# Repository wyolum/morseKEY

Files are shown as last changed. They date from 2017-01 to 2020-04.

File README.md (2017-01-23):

# morseKEY
Morse Code USB Keyboard, from https://mitxela.com/projects/morse_code_usb_keyboard_mk_ii

Morse Key presents itself as a USB keyboard. Typing provides audible feedback via Buzzer, and morse keystrokes get typed on the computer.

## kicad

* [kicad](/kicad) - Main hardware design files. Schematic, Layout etc.

## fabricate

* [fabricate](/fabricate) - 3D CAD files / assembly files

## code

* [code](/code) - FW code

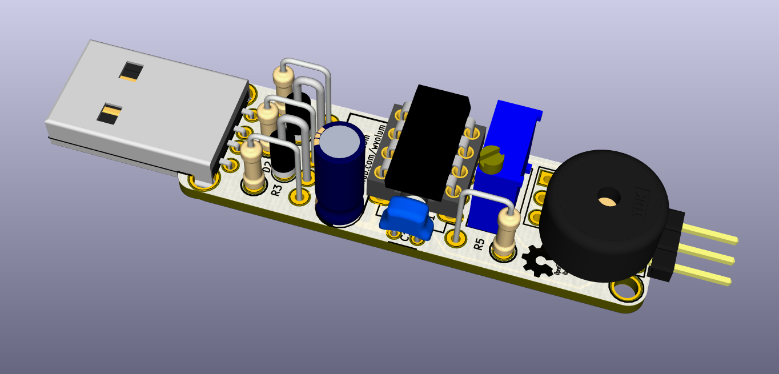
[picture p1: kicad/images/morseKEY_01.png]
morseKEY_top


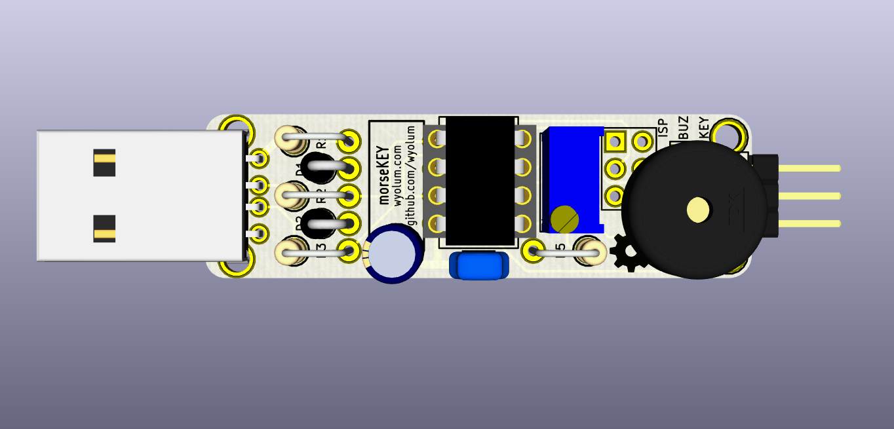
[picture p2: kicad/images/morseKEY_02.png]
morseKEY_bot


License
-------
[CERN Open Hardware Licence v1.2 ]

[CERN Open Hardware Licence v1.2 ]:http://www.ohwr.org/attachments/2388/cern_ohl_v_1_2.txt

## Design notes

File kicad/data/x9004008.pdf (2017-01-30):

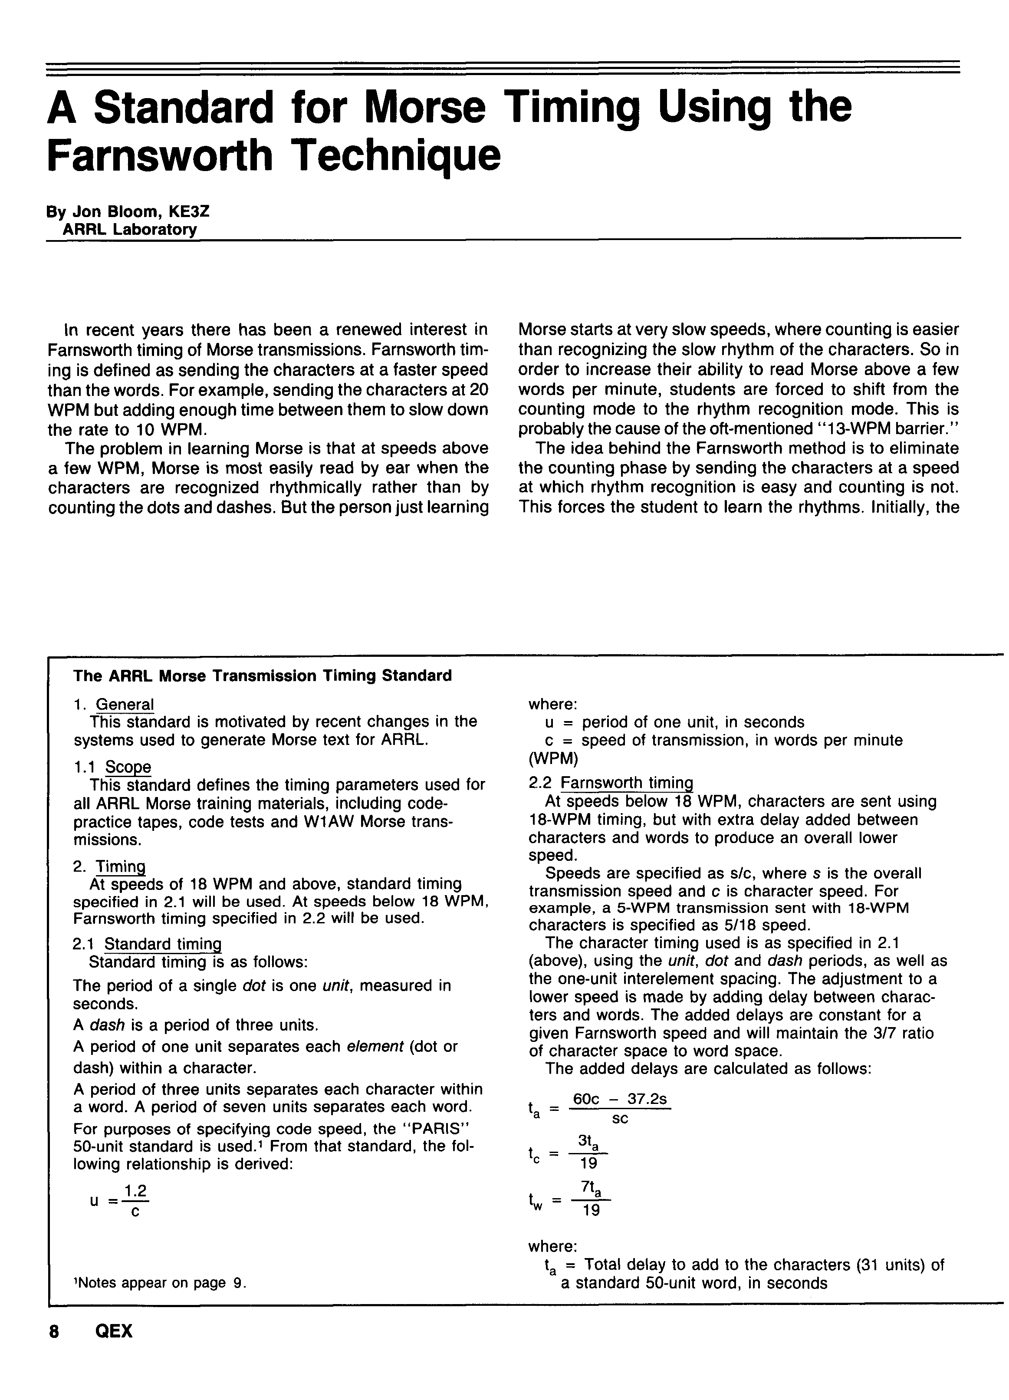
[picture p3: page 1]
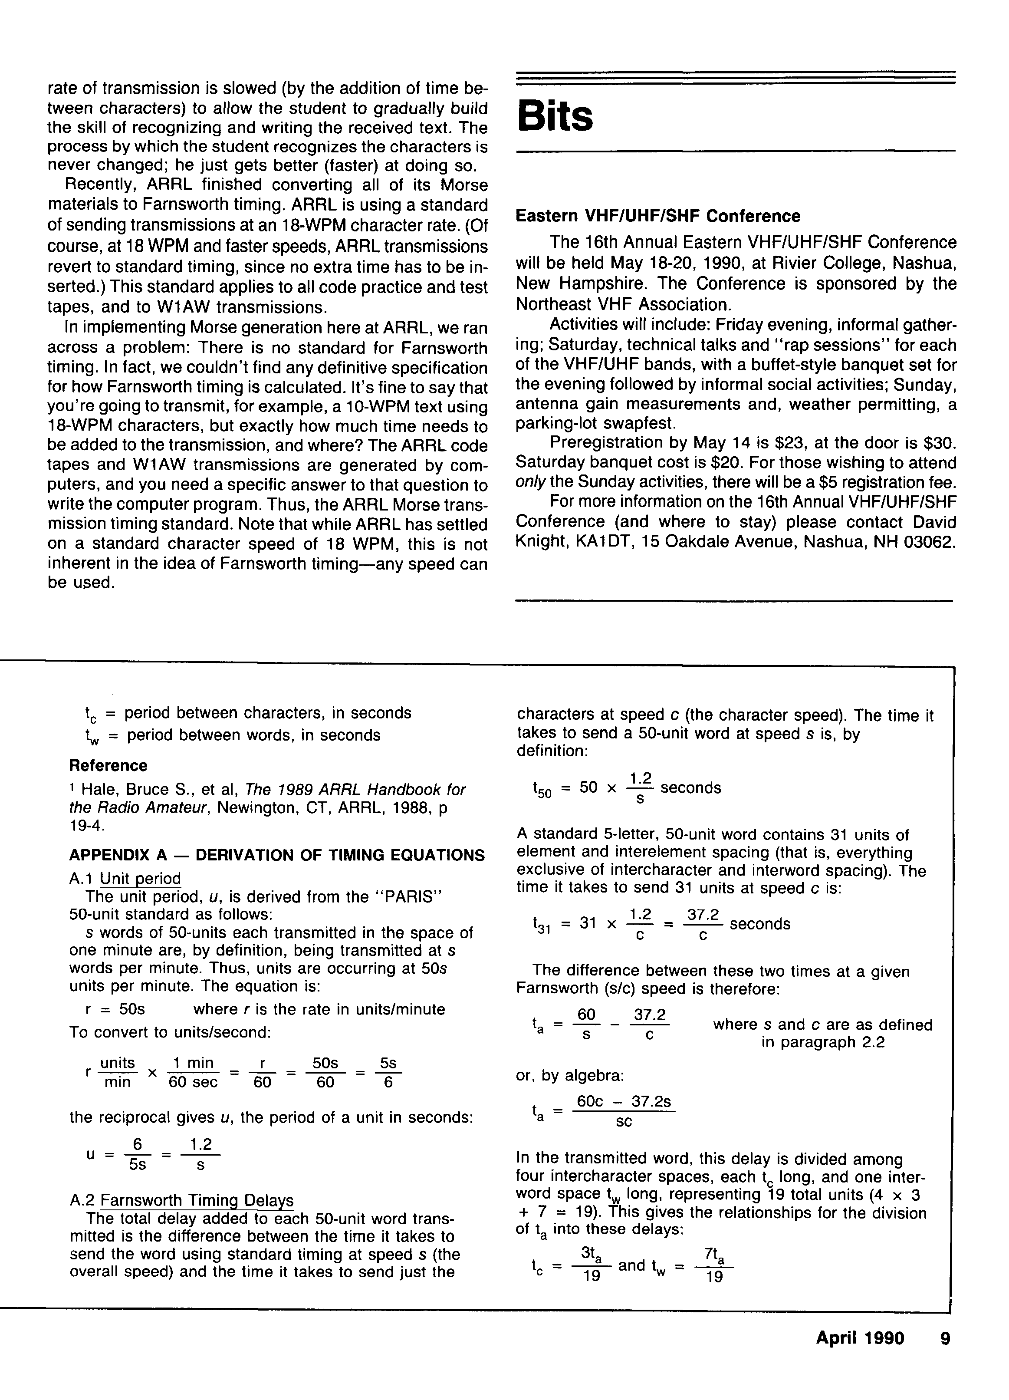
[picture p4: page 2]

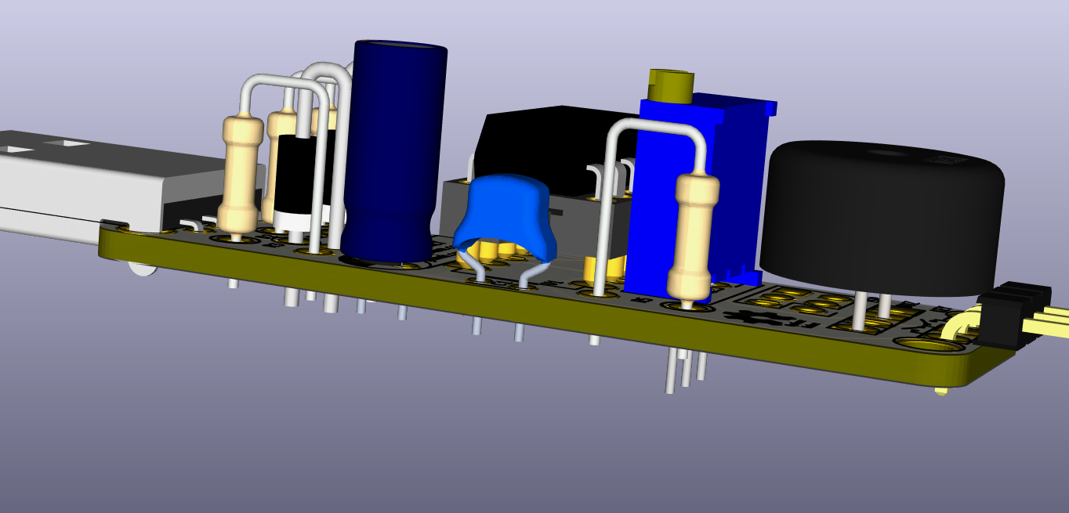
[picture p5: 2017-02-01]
kicad/images/morseKEY_03.png

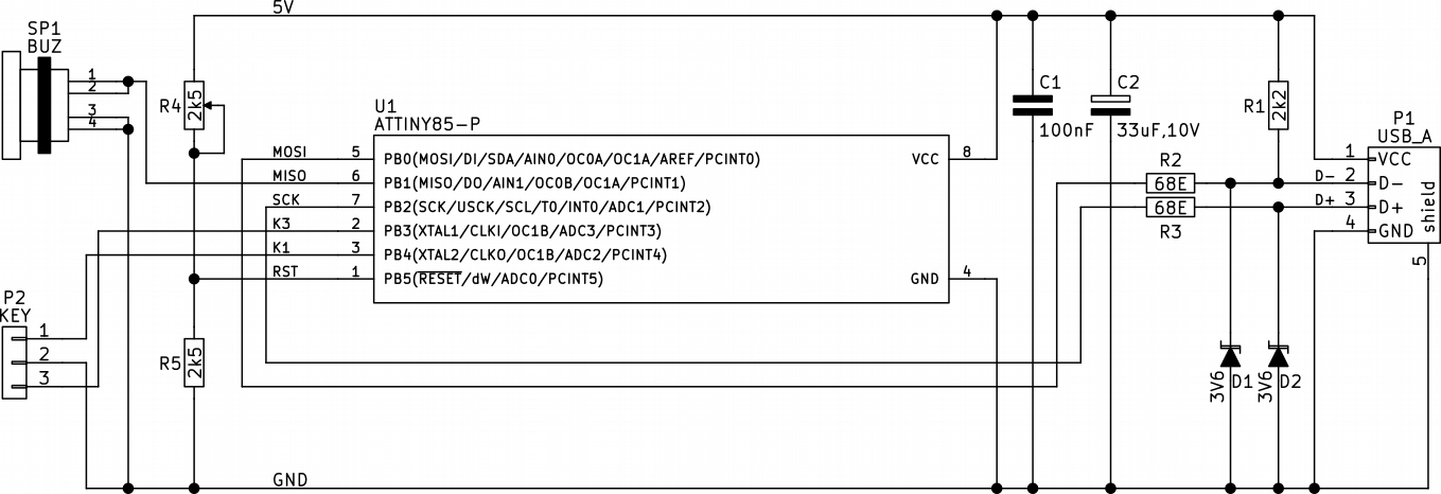
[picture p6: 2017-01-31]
kicad/pdf/morseKEY.sch.jpg

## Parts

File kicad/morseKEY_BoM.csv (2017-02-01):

Id | Designator | Package | Quantity | Designation | Supplier and ref
1 | P3 | Pin_Header_Straight_2x03 | 1 | ISP
2 | C2 | C_Radial_D5_L6_P2.5 | 1 | 33uF,10V
3 | U1 | DIP-8_W7.62mm_LongPads | 1 | ATTINY85-P
4 | SP1 | Pin_Header_Straight_1x04 | 1 | BUZ
5 | P2 | Pin_Header_Straight_1x03 | 1 | KEY
6 | C1 | C_Disc_D3_P2.5 | 1 | 100nF
7 | R4 | res_vert | 1 | 1k5
8 | G1 | OSHW_logo_notext | 1 | OSHW-LOGO
9 | D1,D2 | Diode_DO-41_SOD81_Vertical_KathodeUp_2 | 2 | 3V6
10 | R1 | Resistor_Vertical_RM5mm | 1 | 2k2
11 | R2,R3 | Resistor_Vertical_RM5mm | 2 | 68E
12 | R5 | Resistor_Vertical_RM5mm | 1 | 3k3
13 | G2 | morseKEY | 1 | CKT
14 | P4,P5 | 1pin | 2 | MTG
15 | P1 | USB_A_up2-ah-th | 1 | USB_A

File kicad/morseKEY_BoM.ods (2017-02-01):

Id | Designator | Package | Quantity | Designation | Mfr P/N | Digikey P/N | Link
1 | C1 | Disc, 2.5mm/0.1” pitch | 1 | 100nF | C320C104K5R5TA | 399-4264-ND | http://www.digikey.com/product-detail/en/kemet/C320C104K5R5TA/399-4264-ND/818040
2 | C2 | Radial, 5mm dia, 2.5mm/0.1” pitch | 1 | 33uF,10V | 860020473007 | 732-8824-1-ND | http://www.digikey.com/product-detail/en/wurth-electronics-inc/860020473007/732-8824-1-ND/5728769
3 | D1,D2 | Diode, DO-41 | 2 | 3V6 | 1N5227B | 1N5227B-ND | http://www.digikey.com/product-detail/en/fairchild-on-semiconductor/1N5227B/1N5227B-ND/977563
4 | P1 | USB_A_up2-ah-th | 1 | USB_A | UP2-AH-1-TH | 102-3996-ND | http://www.digikey.com/product-detail/en/cui-inc/UP2-AH-1-TH/102-3996-ND/6187911
5 | P2 | Pin_Header_Straight_1x03 | 1 | KEY | -- | -- | --
6 | P3 | Pin_Header_Straight_2x03 | 1 | ISP | -- | -- | --
7 | R1 | Resistor, 1/4W | 1 | 2k2 | CF18JT2K20 | CF18JT2K20CT-ND | http://www.digikey.com/product-detail/en/stackpole-electronics-inc/CF18JT2K20/CF18JT2K20CT-ND/2022750
8 | R2,R3 | Resistor, 1/4W | 2 | 68E | CF18JT68R0 | CF18JT68R0CT-ND | http://www.digikey.com/product-detail/en/stackpole-electronics-inc/CF18JT68R0/CF18JT68R0CT-ND/2022714
9 | R4 | Trimpot, vertical, in-line leads | 1 | 1k5 | PV36W202C01B00 | 490-2880-ND | http://www.digikey.com/product-detail/en/bourns-inc/PV36W202C01B00/490-2880-ND/666507
10 | R5 | Resistor, 1/4W | 1 | 3k3 | CF18JT3K30 | CF18JT3K30CT-ND | http://www.digikey.com/product-detail/en/stackpole-electronics-inc/CF18JT3K30/CF18JT3K30CT-ND/2022754
11 | SP1 | Buzzer, Piezo, 12.2mm dia, 5mm pitch | 1 | BUZ | PS1440P02BT | 445-5242-1-ND | http://www.digikey.com/product-detail/en/tdk-corporation/PS1440P02BT/445-5242-1-ND/2236832
12 | U1 | DIP-8 | 1 | ATTINY85-P | ATTINY85-20PU | ATTINY85-20PU-ND | http://www.digikey.com/product-detail/en/microchip-technology/ATTINY85-20PU/ATTINY85-20PU-ND/735469
13 | UI_socket | socket, DIP-8 | 1 | -- | ED08DT | ED3044-5-ND | http://www.digikey.com/product-detail/en/on-shore-technology-inc/ED08DT/ED3044-5-ND/4147594

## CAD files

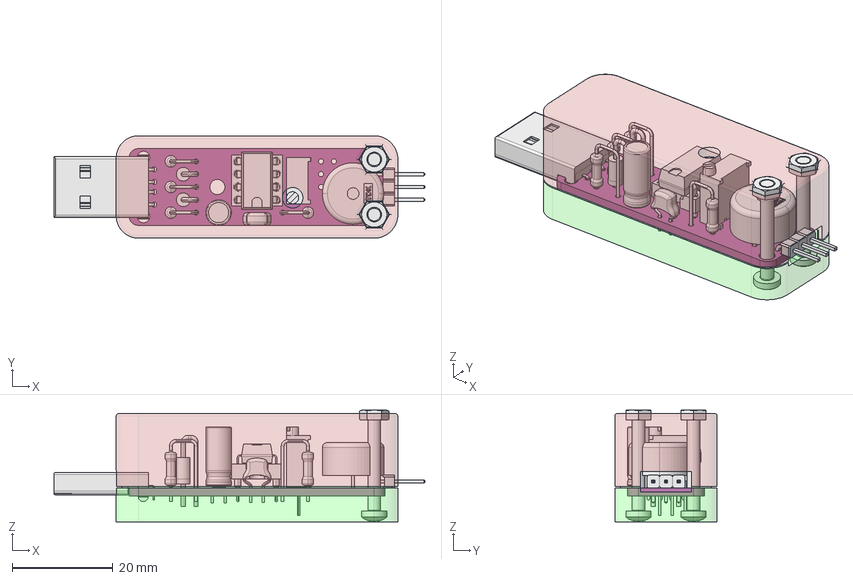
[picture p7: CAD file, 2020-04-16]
fabricate/morseKEY.FCStd
73.6 x 20.3 x 22.2 mm
bottom
top
M2.5x20-Screw
M2.5x20-Screw001
M2.5-Nut
M2.5-Nut001
Pcb_ee89
cap_elco_R100_D200_H460
ic_dip_8
PS1240P02BT003
PS1240P02BT004
PS1240P02BT005
header_Male_RA_Low_3Pin
cap_cer_FK18X5R1E474K
trimpot_vert
diode_vert x 2
res_vert x 4
usb_a

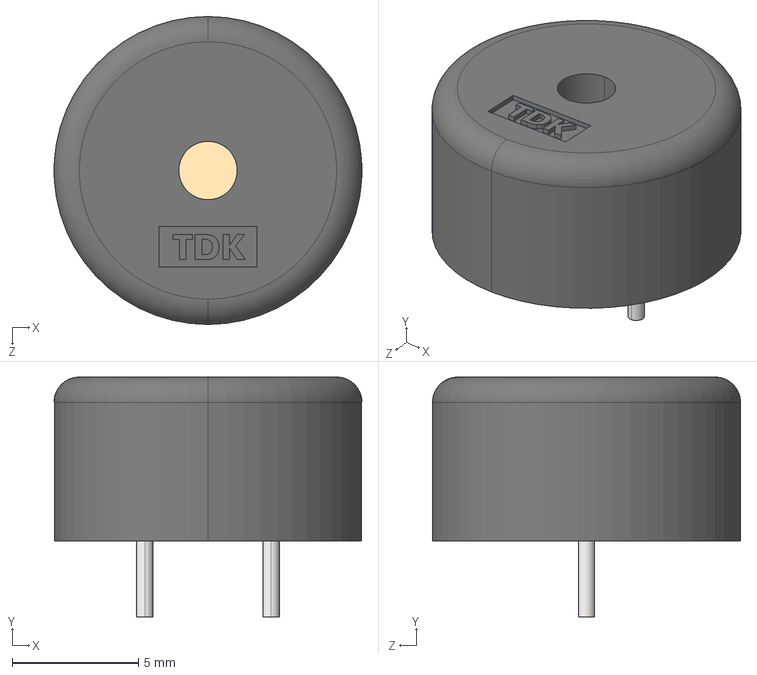
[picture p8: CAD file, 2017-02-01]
kicad/3d/piezo_PS1240P02BT.step
12.2 x 9.50 x 12.2 mm

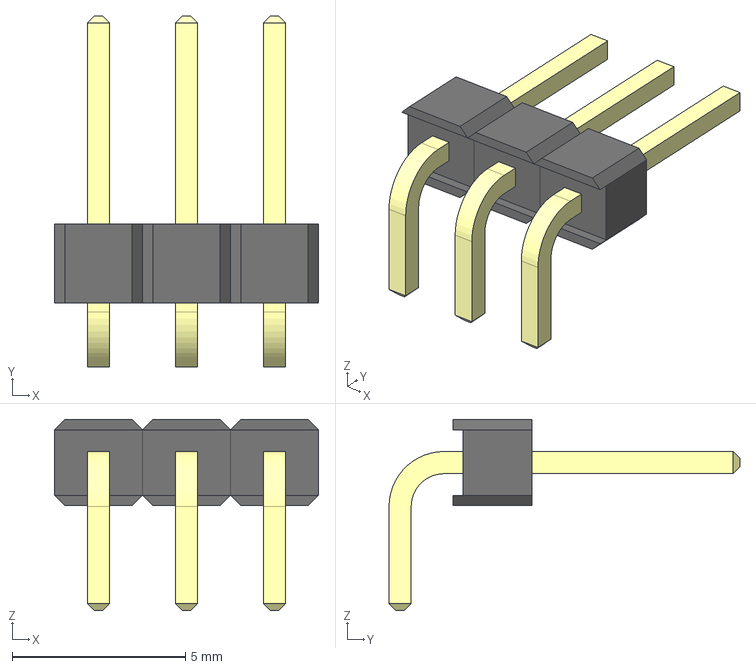
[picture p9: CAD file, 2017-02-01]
kicad/3d/header_Male_RA_Low_3Pin.step
7.62 x 10.1 x 5.52 mm

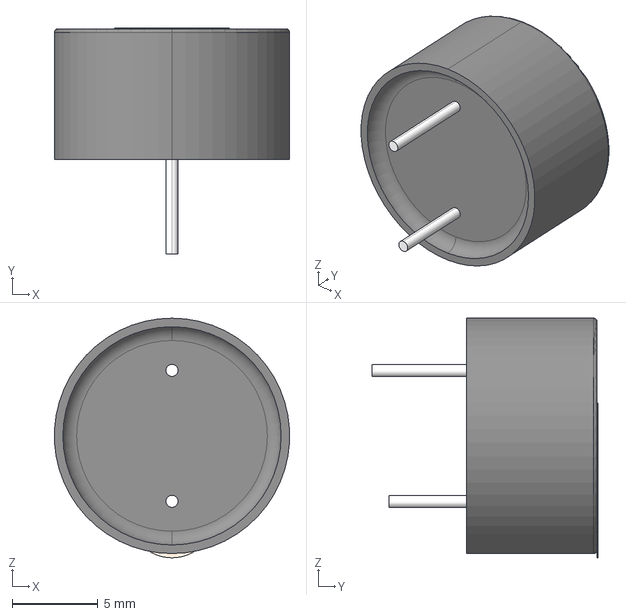
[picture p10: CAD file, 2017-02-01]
kicad/3d/piezo_CPE-164.stp
13.7 x 13.2 x 13.9 mm

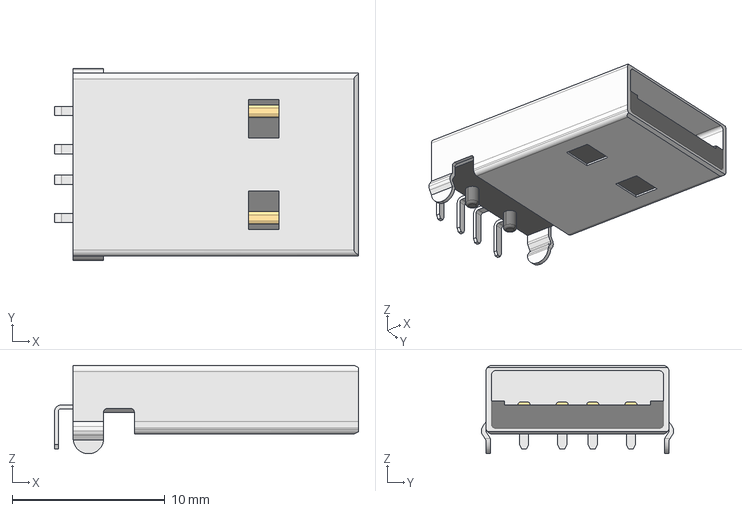
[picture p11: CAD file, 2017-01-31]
kicad/3d/usb_a.step
19.9 x 12.6 x 5.80 mm

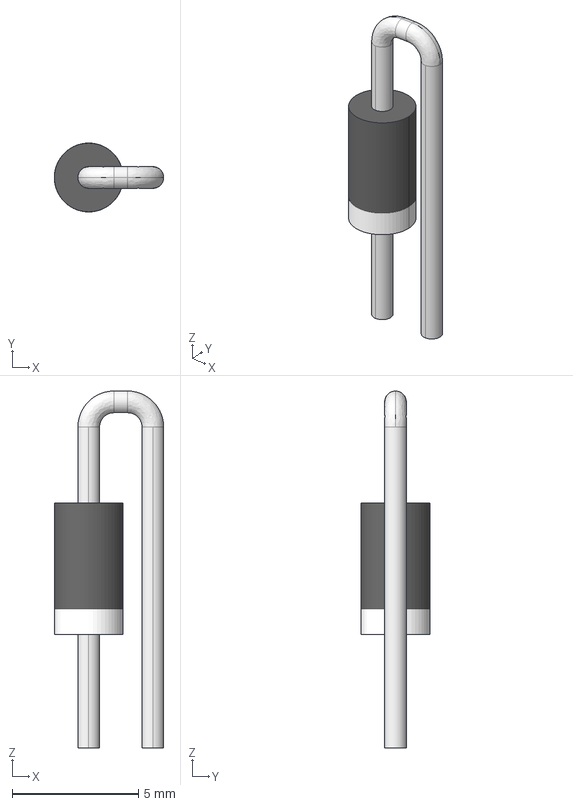
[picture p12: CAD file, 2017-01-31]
kicad/3d/diode_vert.step
4.33 x 2.73 x 14.1 mm

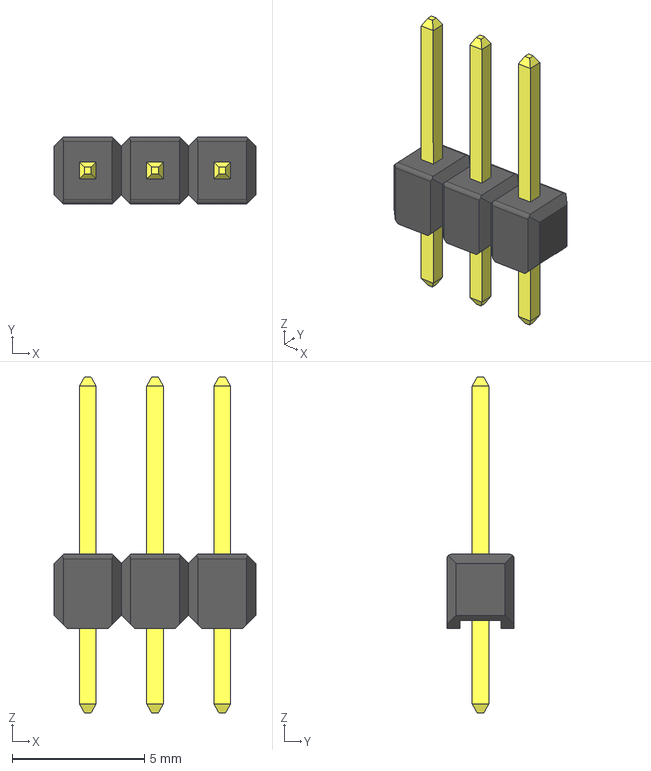
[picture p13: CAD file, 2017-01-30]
kicad/3d/header_1x3_TH_2_54mm.step
7.62 x 2.54 x 12.7 mm

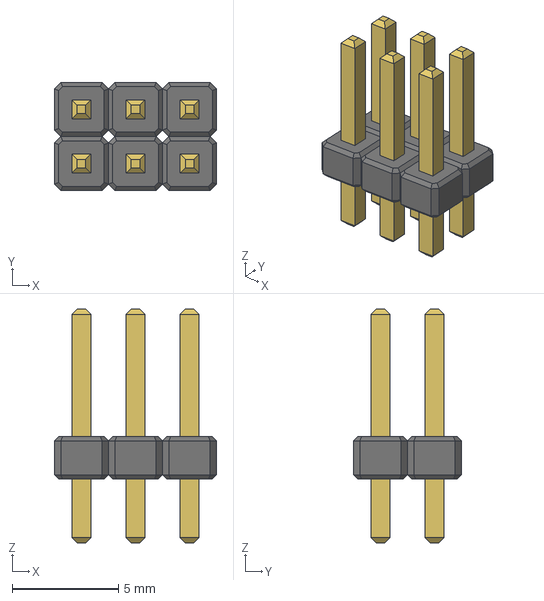
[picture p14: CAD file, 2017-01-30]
kicad/3d/header_2x3_TH_2_54mm.step
7.62 x 5.08 x 11.0 mm

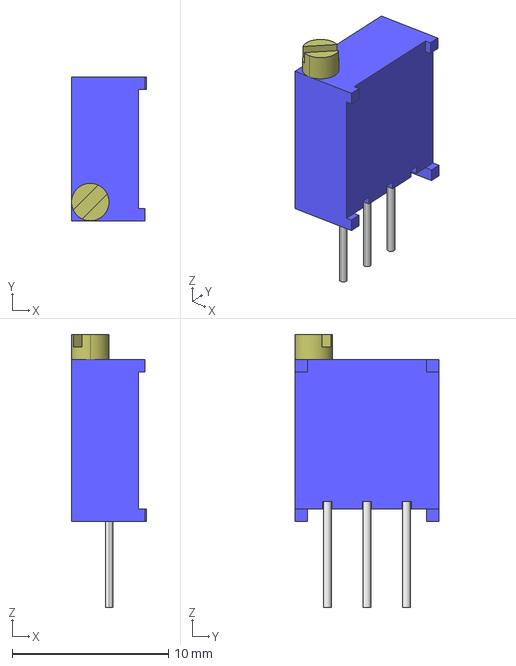
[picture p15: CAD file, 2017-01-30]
kicad/3d/trimpot_vert.step
4.80 x 9.20 x 17.5 mm

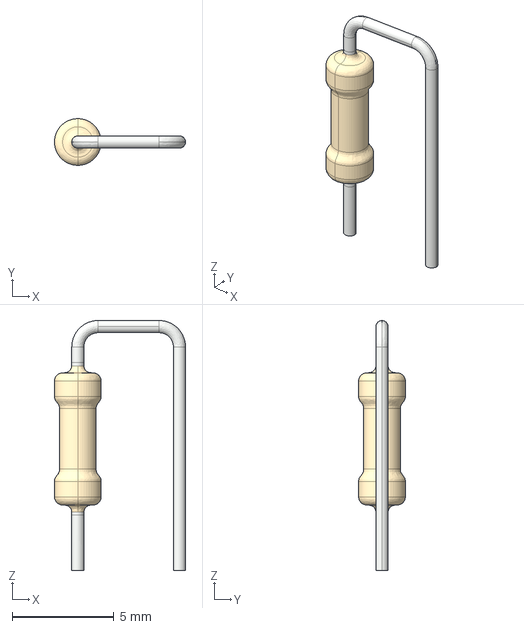
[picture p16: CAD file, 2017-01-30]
kicad/3d/res_vert.step
6.45 x 2.30 x 12.3 mm

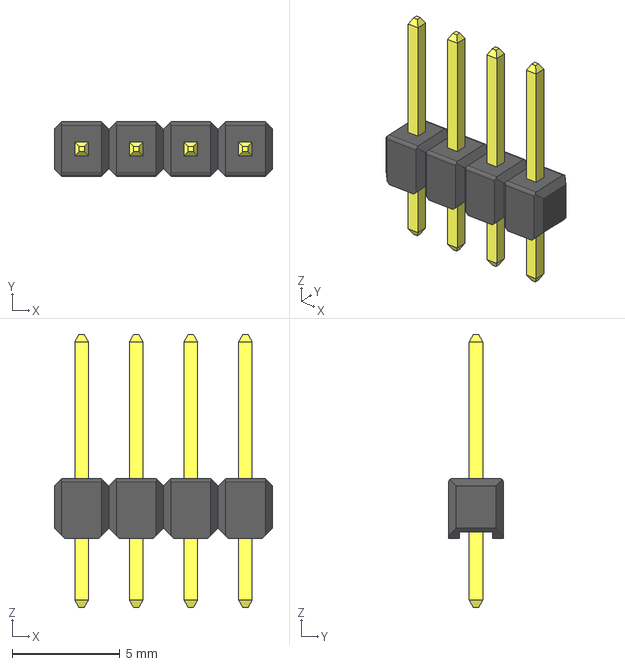
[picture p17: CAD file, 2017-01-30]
kicad/3d/header_1x4_TH_2_54mm.step
10.2 x 2.54 x 12.7 mm

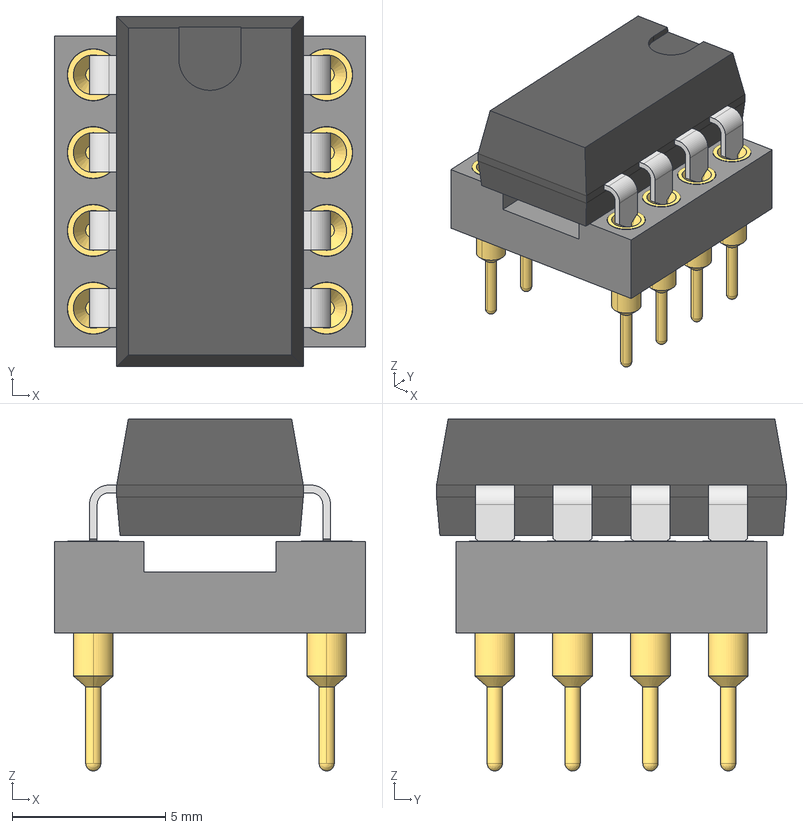
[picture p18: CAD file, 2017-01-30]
kicad/3d/ic_dip_8.step
10.2 x 11.4 x 11.5 mm

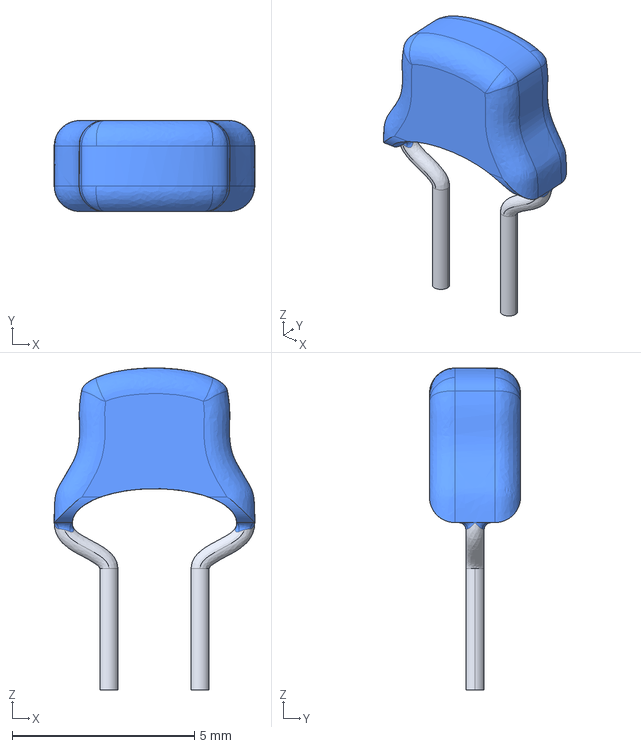
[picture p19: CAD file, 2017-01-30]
kicad/3d/cap_cer_FK18X5R1E474K.step
5.50 x 2.50 x 8.83 mm

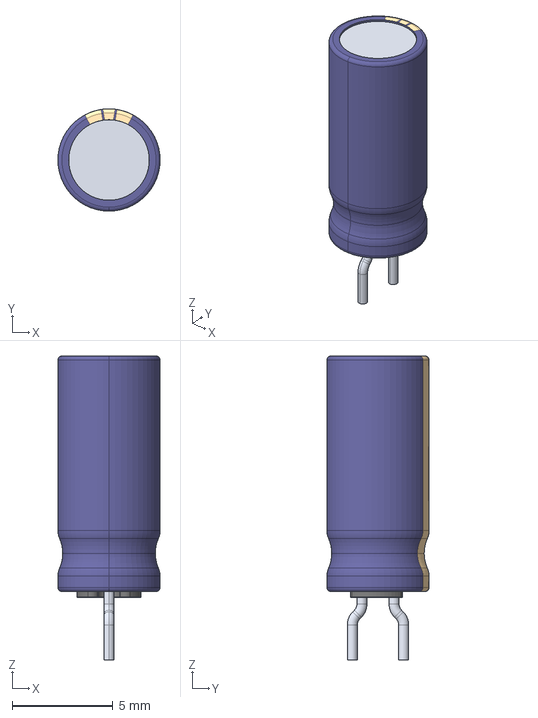
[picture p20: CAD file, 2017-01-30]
kicad/3d/cap_elco_R100_D200_H460.step
5.08 x 5.08 x 15.1 mm

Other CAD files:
kicad/3d/PS1240P02BT.step
kicad/3d/archive/trimpot_vert.step
kicad/3d/archive/cap_elco_ra.step
kicad/3d/archive/usb_a_th.step
kicad/3d/archive/8pin_0_3x2_54mm_DIP_Socket.step
kicad/3d/archive/DIP8.step
kicad/3d/archive/cap_cer-FK18X5R1E474K.step
kicad/3d/archive/cap_cer_3_5x1_5.step
kicad/3d/archive/cap_elco_R100_D200_H460.step
kicad/3d/archive/cap_elec_6_3x11x2_5mm RA.step
kicad/3d/archive/diode_DO-41_vert.step
kicad/3d/archive/pot_vertical.step
kicad/3d/archive/res_vert_0_25W.step

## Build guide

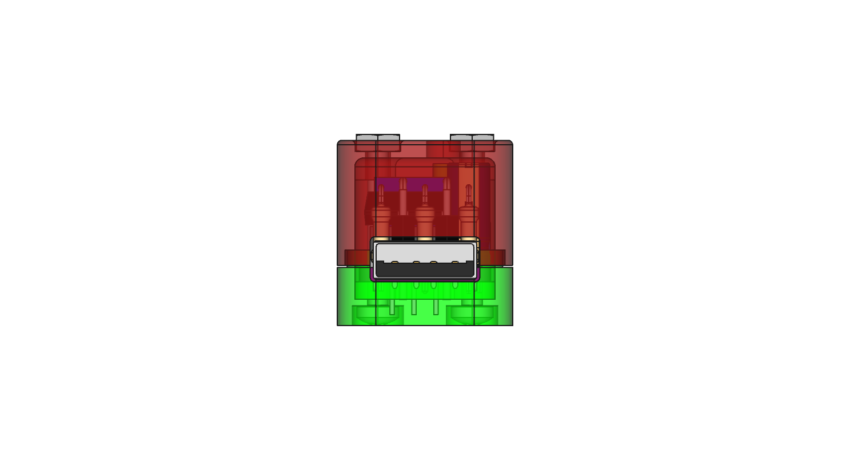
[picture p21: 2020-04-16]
fabricate/renders/morsekey_enc_05.png

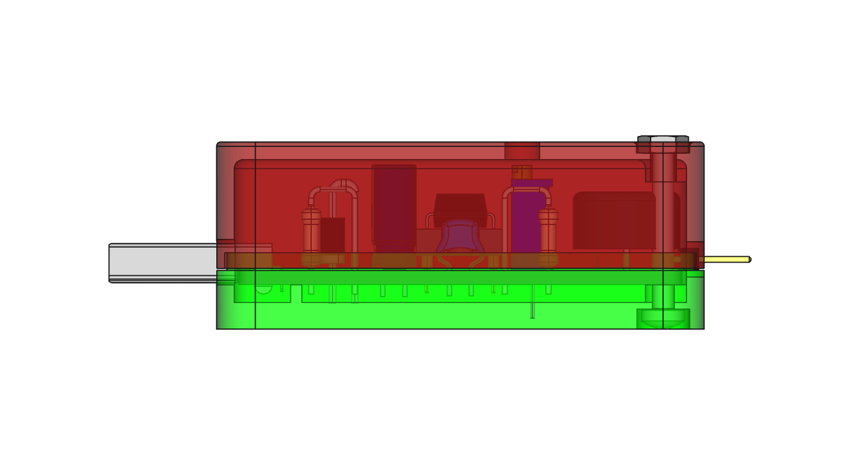
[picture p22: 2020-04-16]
fabricate/renders/morsekey_enc_02.png

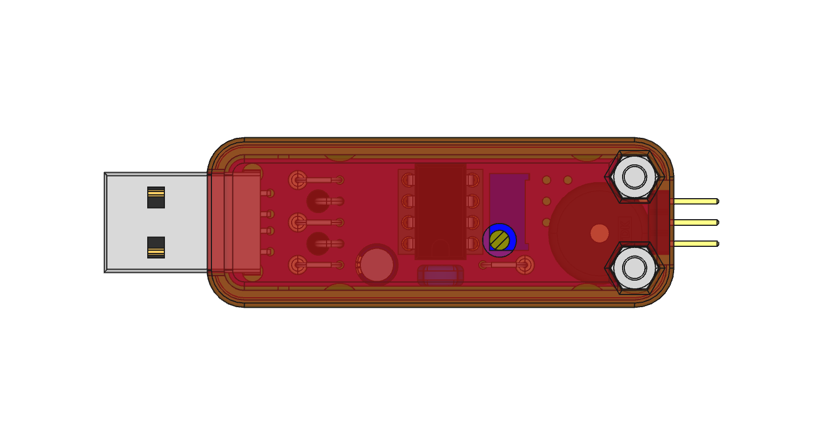
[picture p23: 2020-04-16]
fabricate/renders/morsekey_enc_03.png

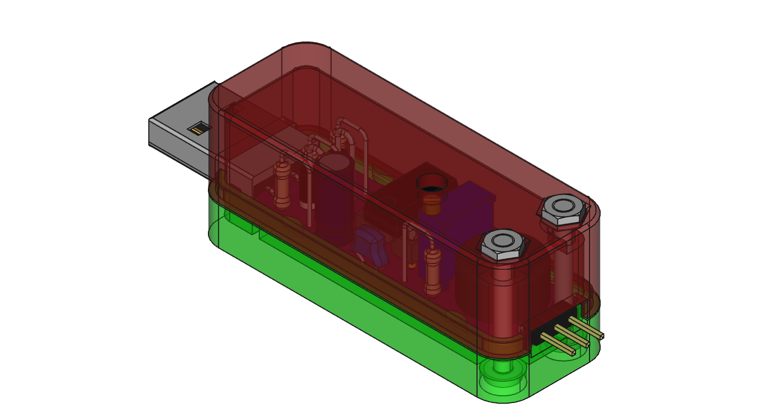
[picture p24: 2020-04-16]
fabricate/renders/morsekey_enc_01.png

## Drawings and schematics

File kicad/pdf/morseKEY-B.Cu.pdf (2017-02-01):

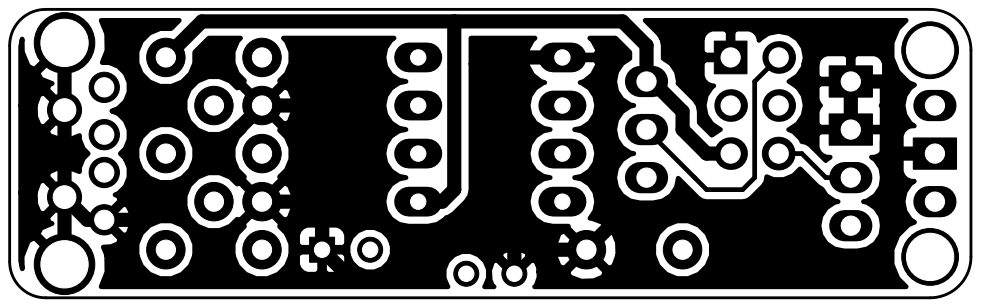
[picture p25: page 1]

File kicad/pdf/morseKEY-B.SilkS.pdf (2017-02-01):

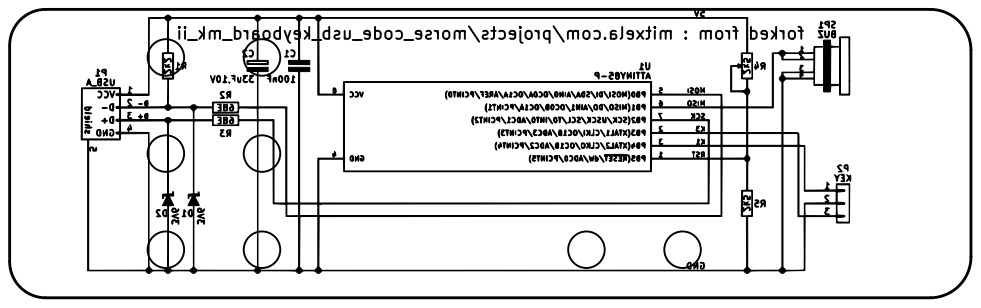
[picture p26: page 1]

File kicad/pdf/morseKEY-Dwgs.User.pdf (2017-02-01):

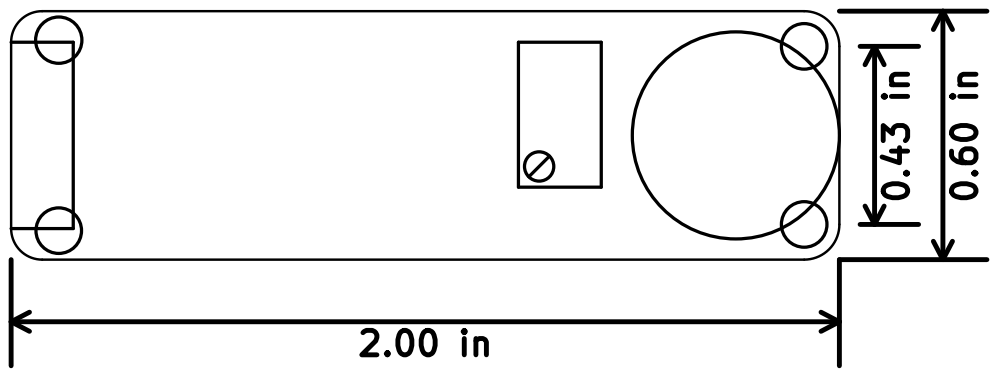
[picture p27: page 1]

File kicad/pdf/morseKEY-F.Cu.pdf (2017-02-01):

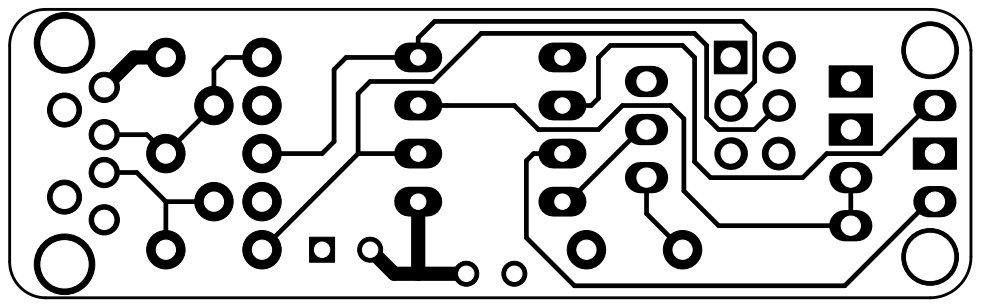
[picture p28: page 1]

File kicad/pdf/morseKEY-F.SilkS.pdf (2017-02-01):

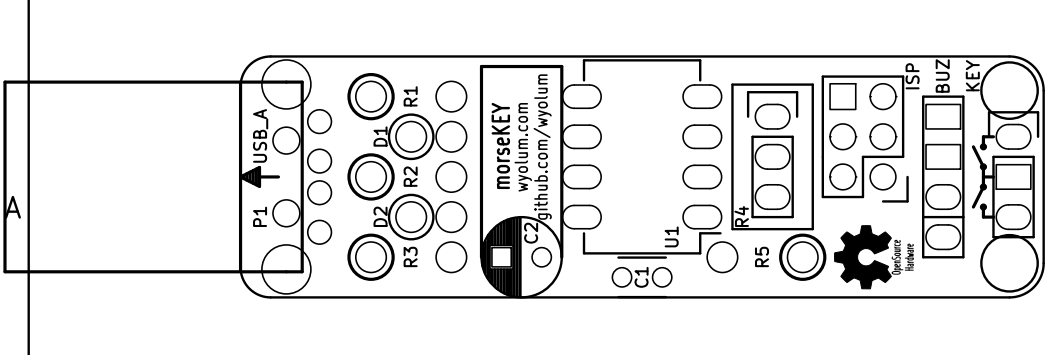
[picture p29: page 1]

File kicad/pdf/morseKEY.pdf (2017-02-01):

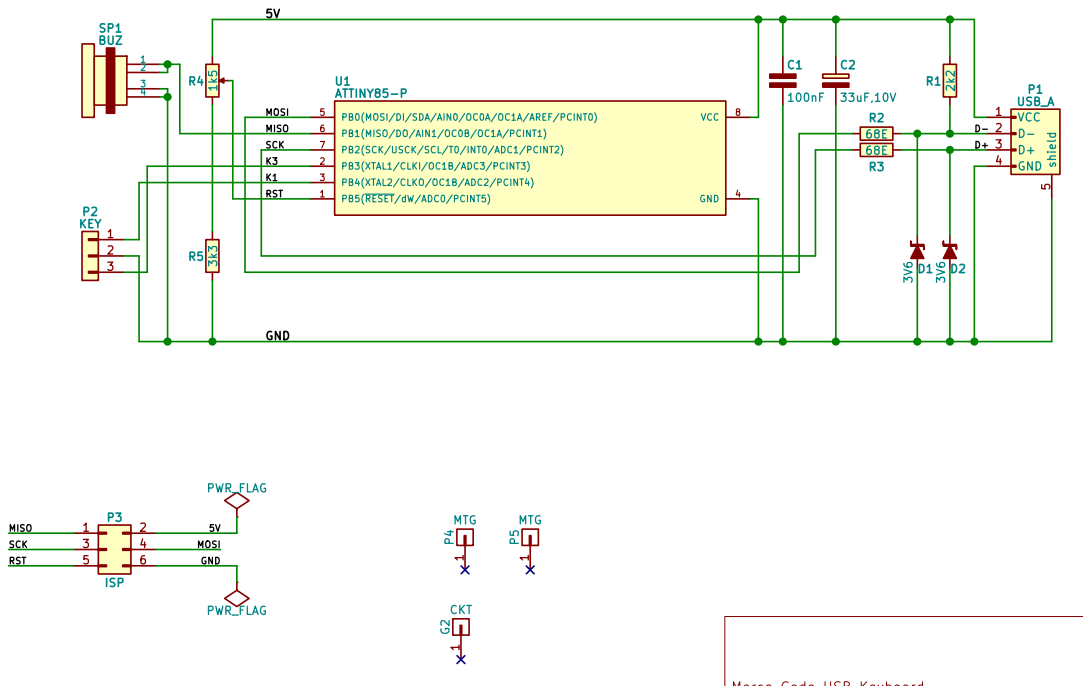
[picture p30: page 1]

Morse Code USB Keyboard
File: morseKEY.sch Sheet: / WyoLum

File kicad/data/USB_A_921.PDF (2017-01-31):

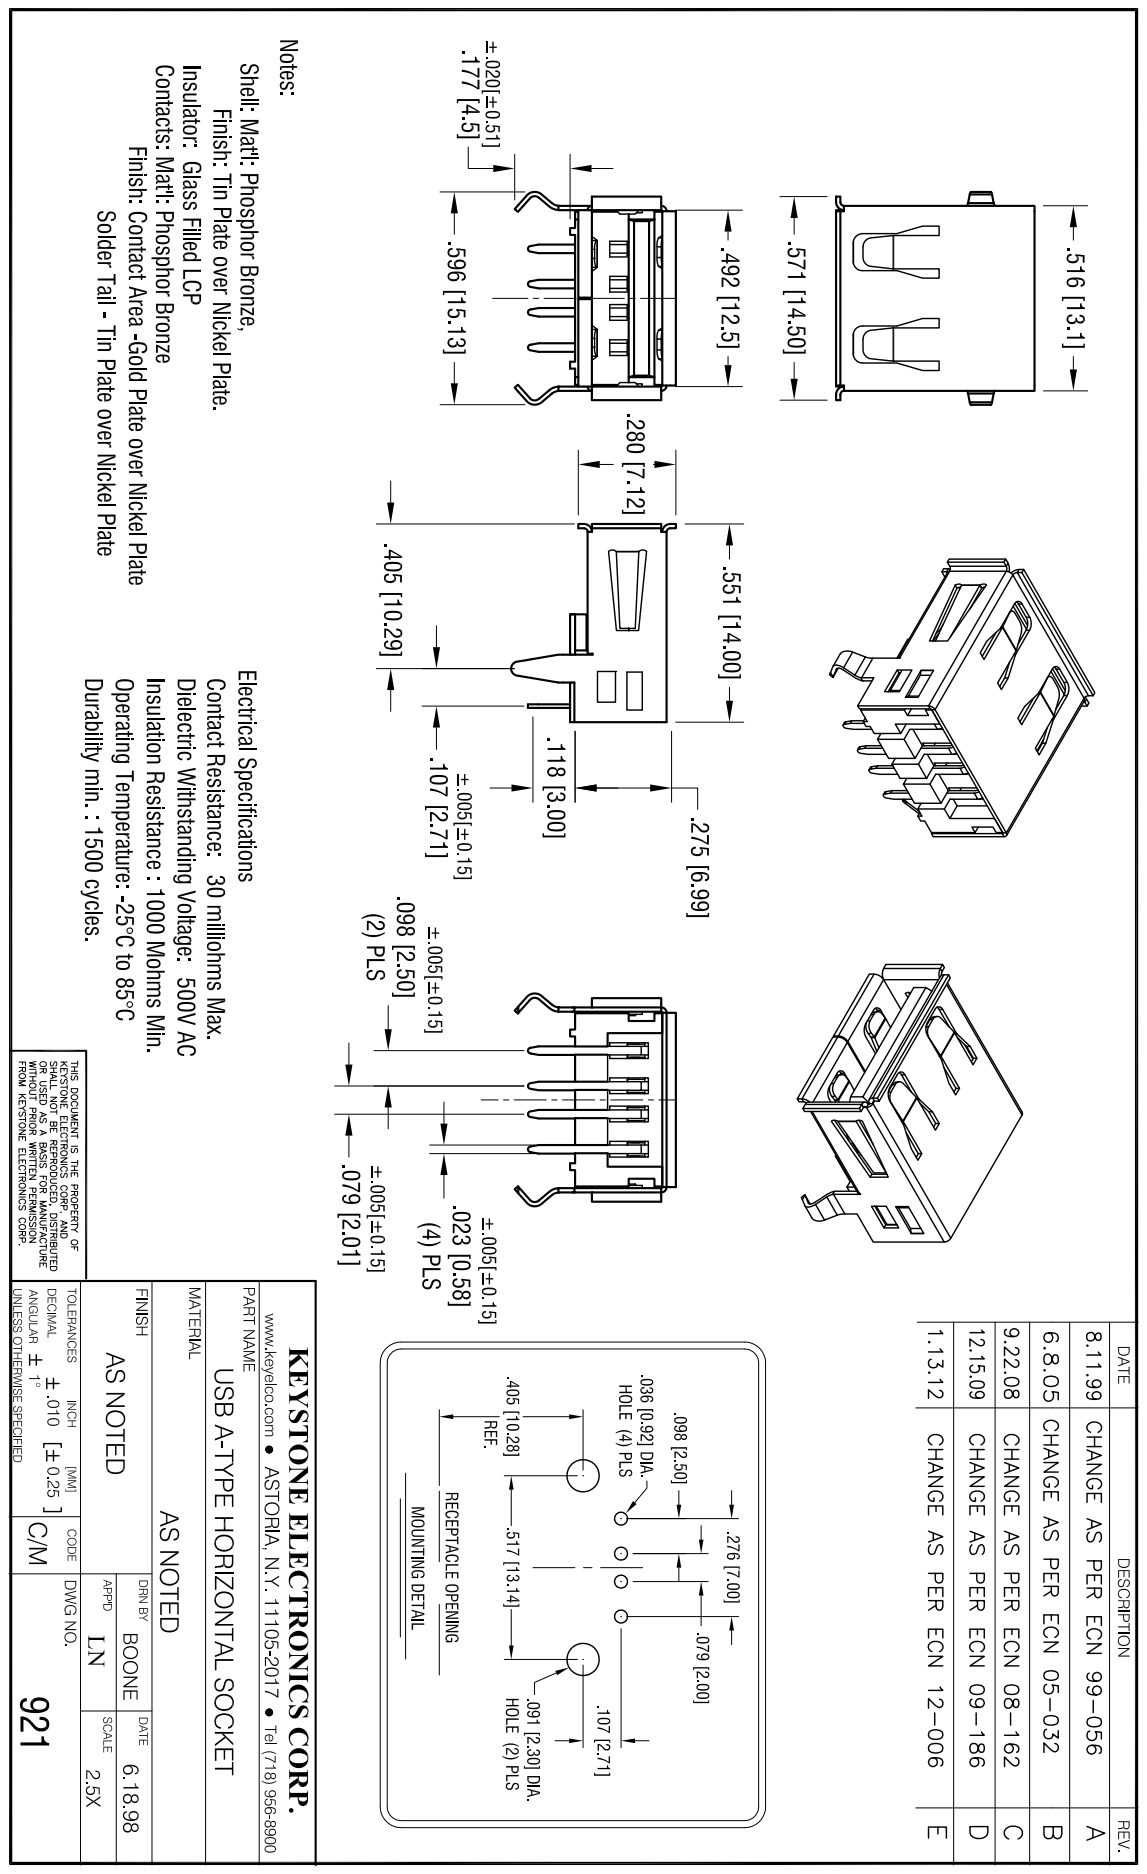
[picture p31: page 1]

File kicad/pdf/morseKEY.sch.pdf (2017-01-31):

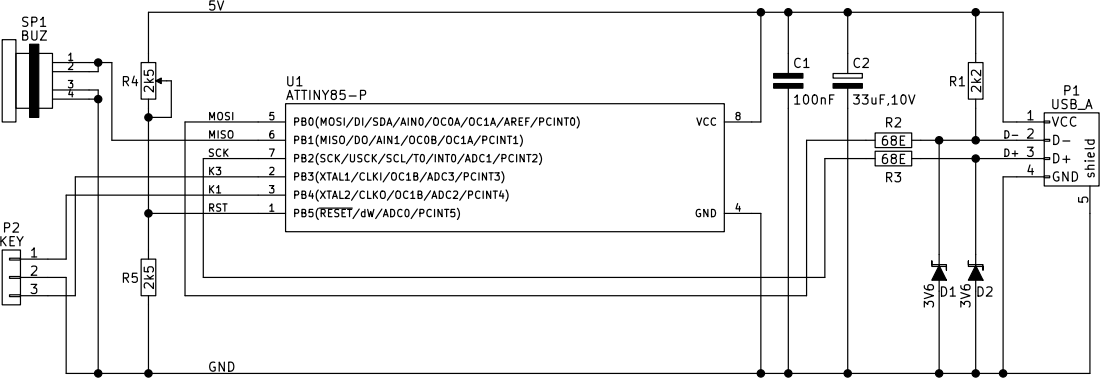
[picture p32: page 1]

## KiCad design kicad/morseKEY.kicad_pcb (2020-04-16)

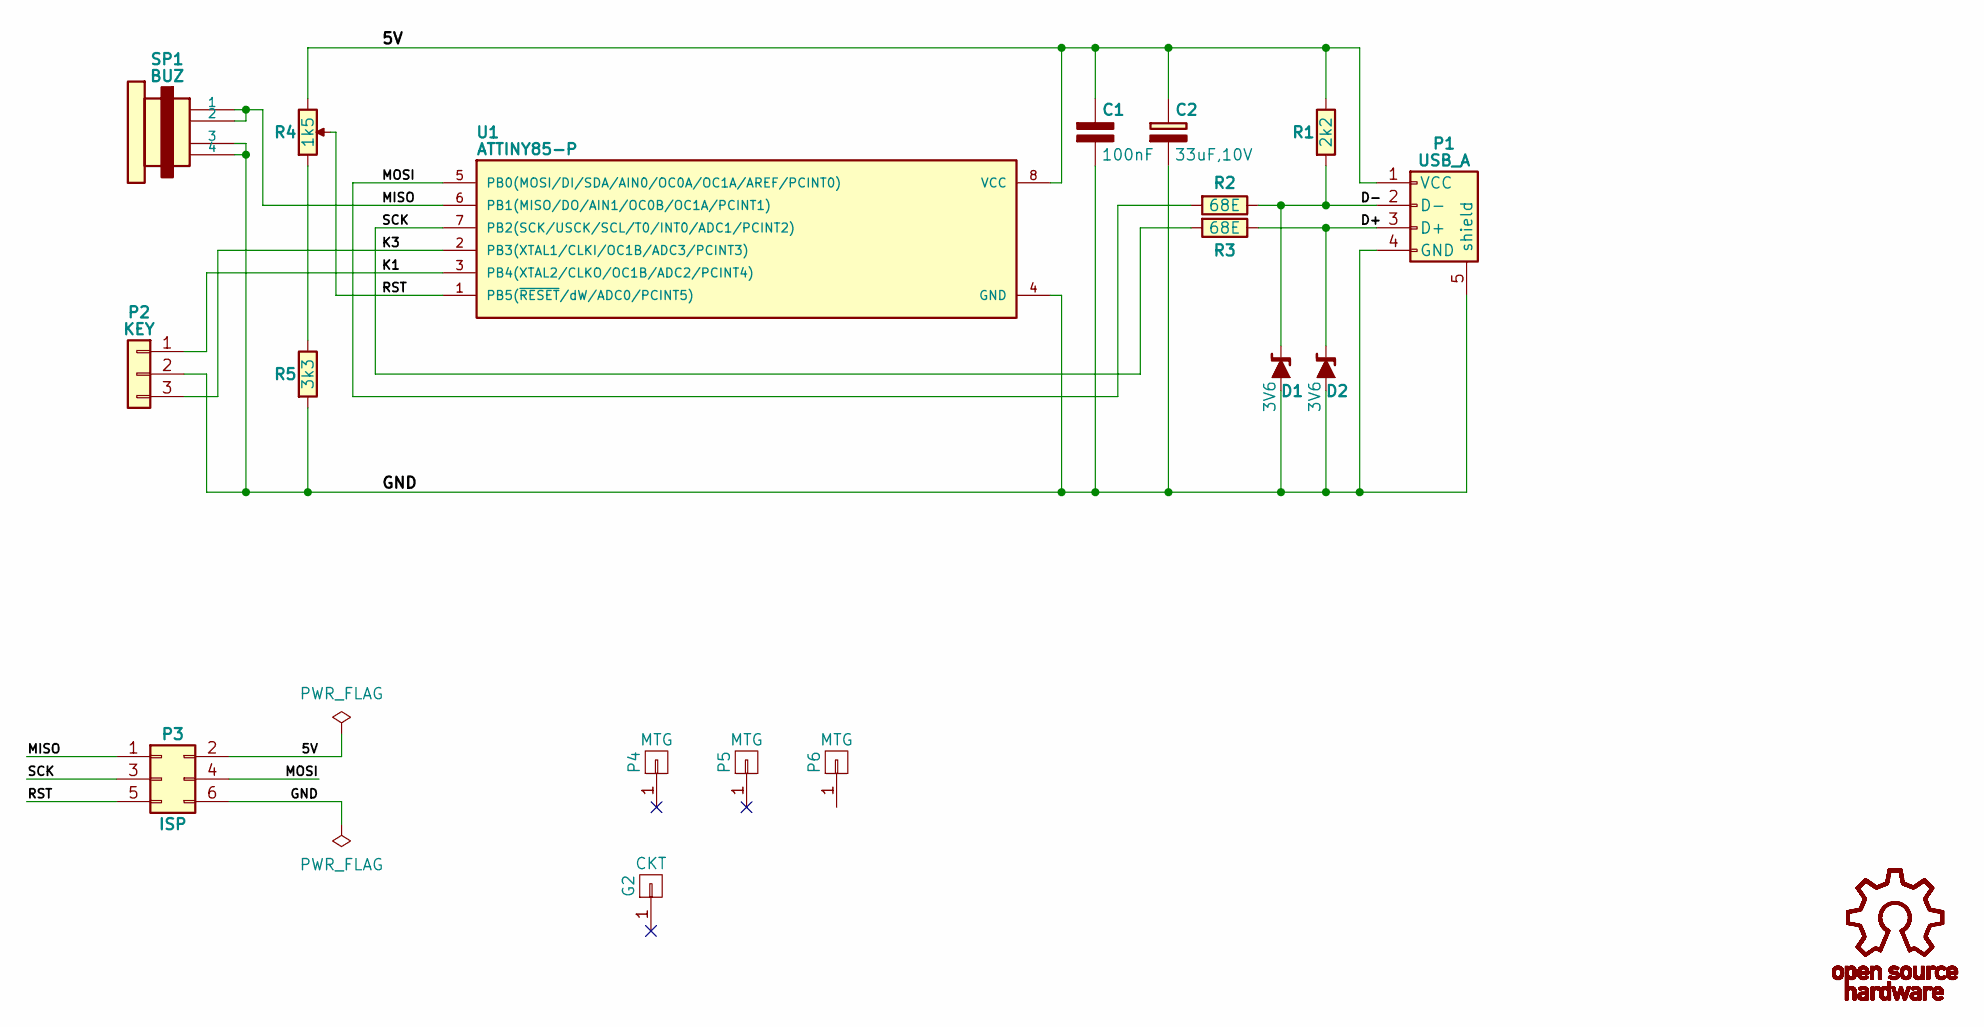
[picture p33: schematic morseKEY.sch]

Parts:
C1: 100nF; C_Disc_D3_P2.5
C2: 33uF,10V; C_Radial_D5_L6_P2.5
D1, D2: 3V6; Diode_DO-41_SOD81_Vertical_KathodeUp_2
G1: OSHW-LOGO; OSHW_logo_notext
G2: CKT; morseKEY
P1: USB_A; USB_A_up2-ah-th
P2: KEY; Pin_Header_Straight_1x03
P3: ISP; Pin_Header_Straight_2x03
P4, P5, P6: MTG; 1pin
R1: 2k2; Resistor_Vertical_RM5mm
R2, R3: 68E; Resistor_Vertical_RM5mm
R4: 1k5; res_vert
R5: 3k3; Resistor_Vertical_RM5mm
SP1: BUZ; Pin_Header_Straight_1x04
U1: ATTINY85-P; DIP-8_W7.62mm_LongPads

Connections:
/5V: C1.1, C2.1, P1.1 (VCC), P3.2, R1.1, R4.1, U1.8 (VCC)
/D+: D2.1 (K), P1.3 (D+), R3.1
/D-: D1.1 (K), P1.2 (D-), R1.2, R2.1
/GND: C1.2, C2.2, D1.2 (A), D2.2 (A), P1.4 (GND), P1.5 (shield), P2.2, P3.6, R5.2, SP1.3, SP1.4, U1.4 (GND)
/K1: P2.1, U1.3 (PB4(XTAL2/CLKO/OC1B/ADC2/PCINT4))
/K3: P2.3, U1.2 (PB3(XTAL1/CLKI/OC1B/ADC3/PCINT3))
/MISO: P3.1, SP1.1, SP1.2, U1.6 (PB1(MISO/DO/AIN1/OC0B/OC1A/PCINT1))
/MOSI: P3.4, R2.2, U1.5 (PB0(MOSI/DI/SDA/AIN0/OC0A/OC1A/AREF/PCI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)
/RST: P3.5, R4.2, U1.1 (PB5(~RESET~/dW/ADC0/PCINT5))
/SCK: P3.3, R3.2, U1.7 (PB2(SCK/USCK/SCL/T0/INT0/ADC1/PCINT2))
unnamed: R4.3, R5.1

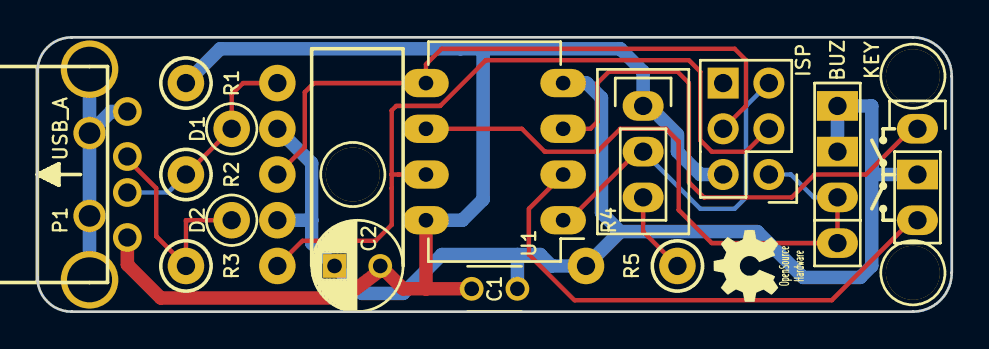
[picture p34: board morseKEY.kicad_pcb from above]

Board: 2 copper layers, 50.8 x 15.2 mm, 18 parts (0 on the bottom side), 11 nets.

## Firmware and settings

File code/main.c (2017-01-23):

/* Morse Code USB Keyboard
 * based on EasyLogger from Objective Development
 * mitxela.com/projects/morse_code_usb_keyboard_mk_ii
 */

#include <avr/io.h>
#include <avr/wdt.h>
#include <avr/eeprom.h>
#include <avr/interrupt.h>
#include <avr/pgmspace.h>
#include <util/delay.h>

#include "usbdrv.h"

/*
Pin assignment:
PB1 = waveform output to piezo
PB4 = key input (active low with pull-up)

PB0, PB2 = USB data lines
*/

#define BIT_PIEZO 1
#define BIT_KEY 4

#define UTIL_BIN4(x)        (uchar)((0##x & 01000)/64 + (0##x & 0100)/16 + (0##x & 010)/4 + (0##x & 1))
#define UTIL_BIN8(hi, lo)   (uchar)(UTIL_BIN4(hi) * 16 + UTIL_BIN4(lo))

#ifndef NULL
#define NULL    ((void *)0)
#endif

/* ------------------------------------------------------------------------- */

const uchar     dashlength  = 9;
const uchar     spacelength = 45;   // longer for farnsworth pause

static uchar    reportBuffer[2];    // buffer for HID reports
static uchar    idleRate;           // in 4 ms units

static uchar    modifier;

static uchar    valueBuffer[16];
static uchar    *nextDigit;

static uchar    symbolBuffer[16];
static uchar    *symbol;


/* ------------------------------------------------------------------------- */

const PROGMEM char usbHidReportDescriptor[USB_CFG_HID_REPORT_DESCRIPTOR_LENGTH] = { /* USB report descriptor */
    0x05, 0x01,                 // USAGE_PAGE (Generic Desktop)
    0x09, 0x06,                 // USAGE (Keyboard)
    0xa1, 0x01,                 // COLLECTION (Application)
    0x05, 0x07,                 // USAGE_PAGE (Keyboard)
    0x19, 0xe0,                 // USAGE_MINIMUM (Keyboard LeftControl)
    0x29, 0xe7,                 // USAGE_MAXIMUM (Keyboard Right GUI)
    0x15, 0x00,                 // LOGICAL_MINIMUM (0)
    0x25, 0x01,                 // LOGICAL_MAXIMUM (1)
    0x75, 0x01,                 // REPORT_SIZE (1)
    0x95, 0x08,                 // REPORT_COUNT (8)
    0x81, 0x02,                 // INPUT (Data,Var,Abs)
    0x95, 0x01,                 // REPORT_COUNT (1)
    0x75, 0x08,                 // REPORT_SIZE (8)
    0x25, 0x65,                 // LOGICAL_MAXIMUM (101)
    0x19, 0x00,                 // USAGE_MINIMUM (Reserved (no event indicated))
    0x29, 0x65,                 // USAGE_MAXIMUM (Keyboard Application)
    0x81, 0x00,                 // INPUT (Data,Ary,Abs)
    0xc0                        // END_COLLECTION
};
/* We use a simplified keyboard report descriptor which does not support the
 * boot protocol. We don't allow setting status LEDs and we only allow one
 * simultaneous key press (except modifiers). We can therefore use short
 * 2 byte input reports.
 * The report descriptor has been created with usb.org's "HID Descriptor Tool"
 * which can be downloaded from http://www.usb.org/developers/hidpage/.
 * Redundant entries (such as LOGICAL_MINIMUM and USAGE_PAGE) have been omitted
 * for the second INPUT item.
 */

/* Keyboard usage values, see usb.org's HID-usage-tables document, chapter
 * 10 Keyboard/Keypad Page for more codes.
 */
#define MOD_CONTROL_LEFT    (1<<0)
#define MOD_SHIFT_LEFT      (1<<1)
#define MOD_ALT_LEFT        (1<<2)
#define MOD_GUI_LEFT        (1<<3)
#define MOD_CONTROL_RIGHT   (1<<4)
#define MOD_SHIFT_RIGHT     (1<<5)
#define MOD_ALT_RIGHT       (1<<6)
#define MOD_GUI_RIGHT       (1<<7)

/* ------------------------------------------------------------------------- */

static void buildReport(void) {
    uchar   key = 0;
    uchar   mod = 0;

    if(nextDigit != NULL){
        key = *nextDigit;
        if (key) mod = modifier;
    }
    reportBuffer[0] = mod;
    reportBuffer[1] = key;
}

static void typechar(char key) {
    if (nextDigit==&valueBuffer[sizeof(valueBuffer)]) {*--nextDigit = 0xff;}/* terminate with 0xff */
    *--nextDigit = 0;
    *--nextDigit = key;
}

static void timerPoll(void) {
    static uchar up;
    static uchar down;

    if(TIFR & (1 << TOV1)){
        TIFR = (1 << TOV1);  // clear overflow

        if(!(PINB & (1 << BIT_KEY))){ //key held
            TCCR0B = 3; //Sound on
            if (down++ ==spacelength+dashlength) {
                down=spacelength;
                typechar(0x2A);
                up=255;
            }
            if (down<spacelength) up=0;
        } else if (down){
            TCCR0B = 0; //Sound off
            if (symbol!=&symbolBuffer[sizeof(symbolBuffer)]){
                if (down>=spacelength) {
                    *symbol=0;
                    while (symbol!=&symbolBuffer[0]) {*--symbol=0;}
                } else if (down<dashlength) {
                    *symbol++ = '.';
                } else {
                    *symbol++ = '-';
                }
            }
            down =0;
        } else {
            TCCR0B = 0; //Sound off
            if (up++ ==255) up=255;
            if (up==1+dashlength) {
                modifier=0;
                //work out key
                if (symbolBuffer[0]=='.') {
                    if (symbolBuffer[1]=='.'){
                        if (symbolBuffer[2]=='.'){
                            if (symbolBuffer[3]=='.'){
                                if (symbolBuffer[4]=='.'){
                                    if (symbolBuffer[5]==0){
                                        typechar(0x22);//5
                                    }
                                } else if (symbolBuffer[4]=='-') {
                                    if (symbolBuffer[5]==0){
                                        typechar(0x21);//4
                                    }
                                } else {
                                    typechar(0x0B);//h
                                }
                            } else if (symbolBuffer[3]=='-') {
                                if (symbolBuffer[4]=='.'){
                                    //if (symbolBuffer[5]==0){
                                        //typechar();//
                                    //}
                                } else if (symbolBuffer[4]=='-') {
                                    if (symbolBuffer[5]==0){
                                        typechar(0x20);//3
                                    }
                                } else {
                                    typechar(0x19);//V
                                }
                            } else {
                                typechar(0x16);//s
                            }
                        } else if (symbolBuffer[2]=='-') {
                            if (symbolBuffer[3]=='.'){
                                if (symbolBuffer[4]==0) {
                                    typechar(0x09);//F
                                }
                            } else if (symbolBuffer[3]=='-') {
                                if (symbolBuffer[4]=='-' && symbolBuffer[5]==0) {
                                    typechar(0x1F);//2
                                } else if (symbolBuffer[4]=='.' && symbolBuffer[5]=='.' && symbolBuffer[6]==0) {
                                    modifier = MOD_SHIFT_RIGHT;
                                    typechar(0x38);// /
                                }
                            } else {
                                typechar(0x18);//U
                            }
                        } else {
                            typechar(0x0C);//i
                        }
                    } else if (symbolBuffer[1]=='-') {
                        
                        if (symbolBuffer[2]=='.'){
                            if (symbolBuffer[3]=='.'){
                                if (symbolBuffer[4]==0) typechar(0x0F);//L
                            } else if (symbolBuffer[3]=='-') {
                                if (symbolBuffer[4]=='.' && symbolBuffer[5]=='-' && symbolBuffer[6]==0) typechar(0x37);//.
                                else if (symbolBuffer[4]=='.' && symbolBuffer[6]==0) {modifier=MOD_SHIFT_RIGHT;typechar(0x2E);}//+
                            } else {
                                typechar(0x15);//R
                            }
                        } else if (symbolBuffer[2]=='-') {
                            if (symbolBuffer[3]=='.'){
                                if (symbolBuffer[4]==0) {
                                    typechar(0x13);//P
                                }
                            } else if (symbolBuffer[3]=='-') {
                                if (symbolBuffer[4]==0) {
                                    typechar(0x0D);//J
                                } else if (symbolBuffer[4]=='-' && symbolBuffer[5]==0){
                                    typechar(0x1E);//1
                                }
                            } else {
                                typechar(0x1A);//W
                            }
                        } else {
                            typechar(0x04);//A
                        }
                    } else {
                        typechar(0x08);//e
                    }
                } else if (symbolBuffer[0]=='-') {
                    if (symbolBuffer[1]=='.'){
                        if (symbolBuffer[2]=='.'){
                            if (symbolBuffer[3]=='.'){
                                if (symbolBuffer[4]=='.'){
                                    if (symbolBuffer[5]==0){
                                        typechar(0x23);//6
                                    }
                                } else if (symbolBuffer[4]=='-') {
                                    if (symbolBuffer[5]==0){
                                        typechar(0x2E);// =
                                    }
                                } else {
                                    typechar(0x05);//B
                                }
                            } else if (symbolBuffer[3]=='-') {
                                if (symbolBuffer[4]=='.'){
                                    if (symbolBuffer[5]==0){
                                        typechar(0x38);// /
                                    }
                                } else if (symbolBuffer[4]=='-') {
                                    //if (symbolBuffer[5]==0){
                                        //typechar();//
                                    //}
                                } else {
                                    typechar(0x1B);//X
                                }
                            } else {
                                typechar(0x07);//D
                            }
                        } else if (symbolBuffer[2]=='-') {
                            if (symbolBuffer[3]=='.'){
                                if (symbolBuffer[4]==0) {
                                    typechar(0x06);//C
                                }
                            } else if (symbolBuffer[3]=='-') {
                                if (symbolBuffer[4]==0) {
                                    typechar(0x1C);//Y
                                }
                            } else {
                                typechar(0x0E);//K
                            }
                        } else {
                            typechar(0x11);//N
                        }
                    } else if (symbolBuffer[1]=='-') {
                        if (symbolBuffer[2]=='.'){
                            if (symbolBuffer[3]=='.'){
                                if (symbolBuffer[4]==0) typechar(0x1D);//Z
                                else if (symbolBuffer[4]=='.' && symbolBuffer[5]==0) typechar(0x24);//7
                                else if (symbolBuffer[4]=='-' && symbolBuffer[5]=='-' && symbolBuffer[6]==0) typechar(0x36);//,
                            } else if (symbolBuffer[3]=='-') {
                                if (symbolBuffer[4]==0) typechar(0x14);//Q
                            } else {
                                typechar(0x0A);//G
                            }
                        } else if (symbolBuffer[2]=='-') {
                            if (symbolBuffer[3]=='.'){
                                if (symbolBuffer[4]=='.' && symbolBuffer[5]==0) {
                                    typechar(0x25);//8
                                }
                            } else if (symbolBuffer[3]=='-') {
                                if (symbolBuffer[4]=='-' && symbolBuffer[5]==0) {
                                    typechar(0x27);// 0
                                } else if (symbolBuffer[4]=='.' && symbolBuffer[5]==0) {
                                    typechar(0x26);// 9
                                }
                            } else {
                                typechar(0x12);//O
                            }
                        } else {
                            typechar(0x10);//M
                        }
                    } else {
                        typechar(0x17);//T
                    }
                }
                
                //empty stack
                *symbol=0;
                while (symbol!=&symbolBuffer[0]) {*--symbol=0;}
            }
            if (up==spacelength && down<spacelength) {
                //type space
                typechar(0x2C);
            }
        }

    }
}


/* ------------------------------------------------------------------------- */

static void timerInit(void) {
    TCCR0A = 0b00010010;
    TCCR0B = 0;
    OCR0A = 64;
    TCCR1 = 0x0b;           /* select clock: 16.5M/1k -> overflow rate = 16.5M/256k = 62.94 Hz */
    modifier=0;
    symbol=&symbolBuffer[sizeof(symbolBuffer)];
    while (symbol!=&symbolBuffer[0]) {*--symbol=0;}
}


/* ------------------------------------------------------------------------- */
/* ------------------------ interface to USB driver ------------------------ */
/* ------------------------------------------------------------------------- */

uchar   usbFunctionSetup(uchar data[8]) {
    usbRequest_t    *rq = (void *)data;

    usbMsgPtr = reportBuffer;
    if((rq->bmRequestType & USBRQ_TYPE_MASK) == USBRQ_TYPE_CLASS){  /* class request type */
        if(rq->bRequest == USBRQ_HID_GET_REPORT){  /* wValue: ReportType (highbyte), ReportID (lowbyte) */
            /* we only have one report type, so don't look at wValue */
            buildReport();
            return sizeof(reportBuffer);
        }else if(rq->bRequest == USBRQ_HID_GET_IDLE){
            usbMsgPtr = &idleRate;
            return 1;
        }else if(rq->bRequest == USBRQ_HID_SET_IDLE){
            idleRate = rq->wValue.bytes[1];
        }
    }else{
        /* no vendor specific requests implemented */
    }
    return 0;
}

/* ------------------------------------------------------------------------- */
/* ------------------------ Oscillator Calibration ------------------------- */
/* ------------------------------------------------------------------------- */

/* Calibrate the RC oscillator to 8.25 MHz. The core clock of 16.5 MHz is
 * derived from the 66 MHz peripheral clock by dividing. Our timing reference
 * is the Start Of Frame signal (a single SE0 bit) available immediately after
 * a USB RESET. We first do a binary search for the OSCCAL value and then
 * optimize this value with a neighboorhod search.
 * This algorithm may also be used to calibrate the RC oscillator directly to
 * 12 MHz (no PLL involved, can therefore be used on almost ALL AVRs), but this
 * is wide outside the spec for the OSCCAL value and the required precision for
 * the 12 MHz clock! Use the RC oscillator calibrated to 12 MHz for
 * experimental purposes only!
 */
static void calibrateOscillator(void) {
    uchar   step = 128;
    uchar   trialValue = 0, optimumValue;
    int     x, optimumDev, targetValue = (unsigned)(1499 * (double)F_CPU / 10.5e6 + 0.5);

    /* do a binary search: */
    do{
        OSCCAL = trialValue + step;
        x = usbMeasureFrameLength();    /* proportional to current real frequency */
        if(x < targetValue)             /* frequency still too low */
            trialValue += step;
        step >>= 1;
    }while(step > 0);
    /* We have a precision of +/- 1 for optimum OSCCAL here */
    /* now do a neighborhood search for optimum value */
    optimumValue = trialValue;
    optimumDev = x; /* this is certainly far away from optimum */
    for(OSCCAL = trialValue - 1; OSCCAL <= trialValue + 1; OSCCAL++){
        x = usbMeasureFrameLength() - targetValue;
        if(x < 0)
            x = -x;
        if(x < optimumDev){
            optimumDev = x;
            optimumValue = OSCCAL;
        }
    }
    OSCCAL = optimumValue;
}
/*
Note: This calibration algorithm may try OSCCAL values of up to 192 even if
the optimum value is far below 192. It may therefore exceed the allowed clock
frequency of the CPU in low voltage designs!
You may replace this search algorithm with any other algorithm you like if
you have additional constraints such as a maximum CPU clock.
For version 5.x RC oscillators (those with a split range of 2x128 steps, e.g.
ATTiny25, ATTiny45, ATTiny85), it may be useful to search for the optimum in
both regions.
*/

void usbEventResetReady(void) {
    /* Disable interrupts during oscillator calibration since
     * usbMeasureFrameLength() counts CPU cycles.
     */
    cli();
    calibrateOscillator();
    sei();
    eeprom_write_byte(0, OSCCAL);   /* store the calibrated value in EEPROM */
}

/* ------------------------------------------------------------------------- */
/* --------------------------------- main ---------------------------------- */
/* ------------------------------------------------------------------------- */

int main(void) {
    uchar   i;
    uchar   calibrationValue;

    calibrationValue = eeprom_read_byte(0); /* calibration value from last time */
    if(calibrationValue != 0xff){
        OSCCAL = calibrationValue;
    }
    usbDeviceDisconnect();
    for(i=0;i<20;i++){  /* 300 ms disconnect */
        _delay_ms(15);
    }
    usbDeviceConnect();
    DDRB |= 1 << BIT_PIEZO;   /* output for buzzer */
    PORTB |= 1 << BIT_KEY;  /* pull-up on key input */
    wdt_enable(WDTO_1S);
    timerInit();
    usbInit();
    sei();
    for(;;){    /* main event loop */
        wdt_reset();
        usbPoll();
        if(usbInterruptIsReady() && nextDigit != NULL){ /* we can send another key */
            buildReport();
            usbSetInterrupt(reportBuffer, sizeof(reportBuffer));
            if(*++nextDigit == 0xff)    /* this was terminator character */
                nextDigit = NULL;
        }
        timerPoll();
    }
    return 0;
}

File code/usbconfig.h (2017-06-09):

/* Name: usbconfig.h
 * Project: AVR USB driver
 * Author: Christian Starkjohann
 * Creation Date: 2007-06-23
 * Tabsize: 4
 * Copyright: (c) 2007 by OBJECTIVE DEVELOPMENT Software GmbH
 * License: GNU GPL v2 (see License.txt) or proprietary (CommercialLicense.txt)
 * This Revision: $Id$
 */

#ifndef __usbconfig_h_included__
#define __usbconfig_h_included__

/* ---------------------------- Hardware Config ---------------------------- */

#define USB_CFG_IOPORTNAME      B
/* This is the port where the USB bus is connected. When you configure it to
 * "B", the registers PORTB, PINB and DDRB will be used.
 */
#define USB_CFG_DMINUS_BIT      0
/* This is the bit number in USB_CFG_IOPORT where the USB D- line is connected.
 * This may be any bit in the port.
 */
#define USB_CFG_DPLUS_BIT       2
/* This is the bit number in USB_CFG_IOPORT where the USB D+ line is connected.
 * This may be any bit in the port. Please note that D+ must also be connected
 * to interrupt pin INT0!
 */
#define USB_CFG_CLOCK_KHZ       (F_CPU/1000)
/* Clock rate of the AVR in MHz. Legal values are 12000, 16000 or 16500.
 * The 16.5 MHz version of the code requires no crystal, it tolerates +/- 1%
 * deviation from the nominal frequency. All other rates require a precision
 * of 2000 ppm and thus a crystal!
 * Default if not specified: 12 MHz
 */

/* ----------------------- Optional Hardware Config ------------------------ */

/* #define USB_CFG_PULLUP_IOPORTNAME   D */
/* If you connect the 1.5k pullup resistor from D- to a port pin instead of
 * V+, you can connect and disconnect the device from firmware by calling
 * the macros usbDeviceConnect() and usbDeviceDisconnect() (see usbdrv.h).
 * This constant defines the port on which the pullup resistor is connected.
 */
/* #define USB_CFG_PULLUP_BIT          4 */
/* This constant defines the bit number in USB_CFG_PULLUP_IOPORT (defined
 * above) where the 1.5k pullup resistor is connected. See description
 * above for details.
 */

/* --------------------------- Functional Range ---------------------------- */

#define USB_CFG_HAVE_INTRIN_ENDPOINT    1
/* Define this to 1 if you want to compile a version with two endpoints: The
 * default control endpoint 0 and an interrupt-in endpoint 1.
 */
#define USB_CFG_HAVE_INTRIN_ENDPOINT3   0
/* Define this to 1 if you want to compile a version with three endpoints: The
 * default control endpoint 0, an interrupt-in endpoint 1 and an interrupt-in
 * endpoint 3. You must also enable endpoint 1 above.
 */
#define USB_CFG_IMPLEMENT_HALT          0
/* Define this to 1 if you also want to implement the ENDPOINT_HALT feature
 * for endpoint 1 (interrupt endpoint). Although you may not need this feature,
 * it is required by the standard. We have made it a config option because it
 * bloats the code considerably.
 */
#define USB_CFG_INTR_POLL_INTERVAL      10
/* If you compile a version with endpoint 1 (interrupt-in), this is the poll
 * interval. The value is in milliseconds and must not be less than 10 ms for
 * low speed devices.
 */
#define USB_CFG_IS_SELF_POWERED         0
/* Define this to 1 if the device has its own power supply. Set it to 0 if the
 * device is powered from the USB bus.
 */
#define USB_CFG_MAX_BUS_POWER           50
/* Set this variable to the maximum USB bus power consumption of your device.
 * The value is in milliamperes. [It will be divided by two since USB
 * communicates power requirements in units of 2 mA.]
 */
#define USB_CFG_IMPLEMENT_FN_WRITE      0
/* Set this to 1 if you want usbFunctionWrite() to be called for control-out
 * transfers. Set it to 0 if you don't need it and want to save a couple of
 * bytes.
 */
#define USB_CFG_IMPLEMENT_FN_READ       0
/* Set this to 1 if you need to send control replies which are generated
 * "on the fly" when usbFunctionRead() is called. If you only want to send
 * data from a static buffer, set it to 0 and return the data from
 * usbFunctionSetup(). This saves a couple of bytes.
 */
#define USB_CFG_IMPLEMENT_FN_WRITEOUT   0
/* Define this to 1 if you want to use interrupt-out (or bulk out) endpoint 1.
 * You must implement the function usbFunctionWriteOut() which receives all
 * interrupt/bulk data sent to endpoint 1.
 */
#define USB_CFG_HAVE_FLOWCONTROL        0
/* Define this to 1 if you want flowcontrol over USB data. See the definition
 * of the macros usbDisableAllRequests() and usbEnableAllRequests() in
 * usbdrv.h.
 */
#ifndef __ASSEMBLER__
extern void usbEventResetReady(void);
#endif
#define USB_RESET_HOOK(isReset)             if(!isReset){usbEventResetReady();}
/* This macro is a hook if you need to know when an USB RESET occurs. It has
 * one parameter which distinguishes between the start of RESET state and its
 * end.
 */
#define USB_CFG_HAVE_MEASURE_FRAME_LENGTH   1
/* define this macro to 1 if you want the function usbMeasureFrameLength()
 * compiled in. This function can be used to calibrate the AVR's RC oscillator.
 */
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

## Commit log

2017-01-30 board layout
    [morseKEY.kicad_pcb, morseKEY.sch]
2017-01-30 3D render
    [8pin_0_3x2_54mm_DIP_Socket.step, DIP8.step, cap_cer-FK18X5R1E474K.step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]
2017-02-01 changed RST resistor divider
    [morseKEY.kicad_pcb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]
2017-02-01 fixed schematic library error
2017-06-21 reverse pinout of USB connector, reroute
    [morseKEY.kicad_pcb]
2017-06-21 update gerbers
    [morseKEY-B.Cu.gbl, morseKEY-B.Mask.gbs, morseKEY-B.SilkS.gbo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]
2020-04-16 morseKEY update for KiCad FreeCAD demo tutorial
    [8pin_0_3x2_54mm_DIP_Socket.step, DIP8.step, PS1240P02BT.step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]

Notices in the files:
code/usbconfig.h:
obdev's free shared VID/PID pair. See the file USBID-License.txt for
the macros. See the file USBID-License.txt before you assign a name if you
